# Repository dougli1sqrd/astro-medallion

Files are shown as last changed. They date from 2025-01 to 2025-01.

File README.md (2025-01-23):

# Astro Medallion

Electronics schematics, PCB layout, and software for the Astro Medallion.

The Astro Medallion is a 12 sided circuit board with LEDs that represent the astrological planets and their positions as a sort of clock. Earth is in the middle of 12 spokes of addressable RGB LEDs, where each spoke represents a sky position in the elliptical - each 30 degree section one of the zodiac signs. The distance along each spoke represents the distance away from the each planet is from the earth. Since it's geocentric planets may sometimes be closer or farther away from each other. Each planet will have a unique color.

There are Warm White LEDs along the edge of the PCB which represents the current field of view from your position on Earth - which rotates around the board once every 24 hours.

The project is a kind of translation of this page: https://ericofftherails.city/astrosim/

The LEDs are controlled by an esp32c3 microcontroller on a development board.

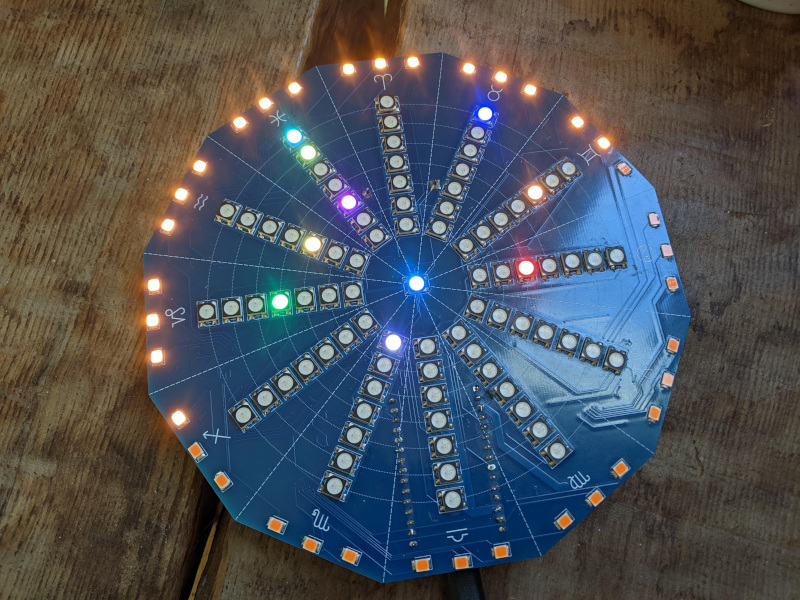
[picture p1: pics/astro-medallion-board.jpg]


# Software

Fundamentally, the software controlling the board needs to:
1. Read the time in the RTC (Real Time Clock) chip on the PCB
2. Calculate Planetary positions
   1. Compute the positions of the planets relative to the earth based on the current time
   2. Compute the "facing" horizon position
3. Update the Display
   1. Send color data to the Addressable LEDs representing where each Planet is with respect to the zodiac sign
   2. Send white LED data representing the current horizon position
4. Sleep, and then awaken in time for the next update

Additionally, the software will have to be configurable mainly in setting the current time. Reading and Writing the current time will go over I2C to the RTC chip on board. This perhaps could be accomplished with a basic serial command line

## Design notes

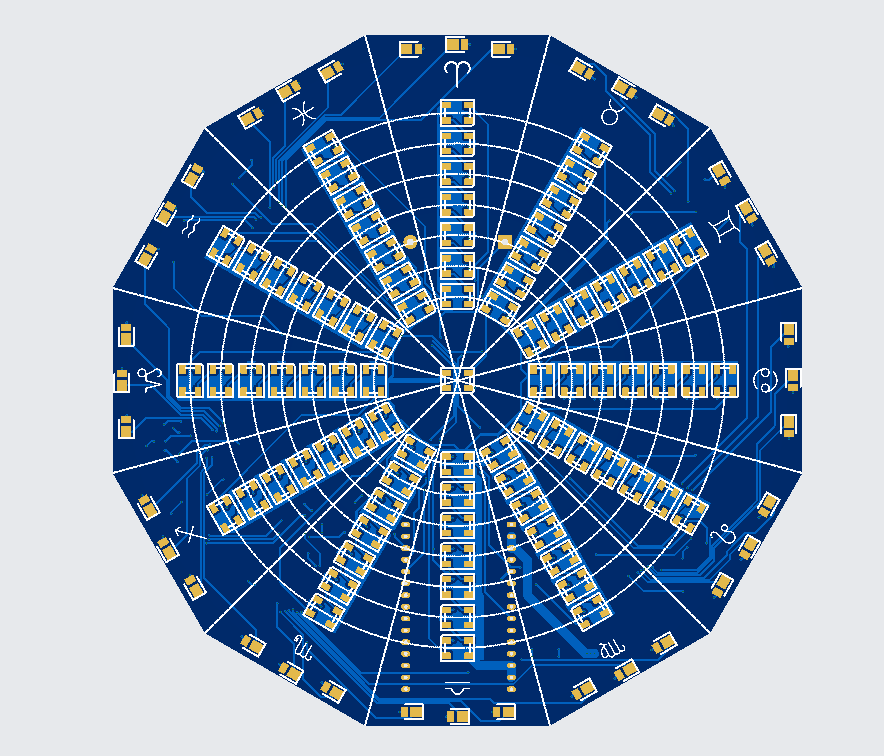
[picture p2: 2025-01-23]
pics/pcb-render.png

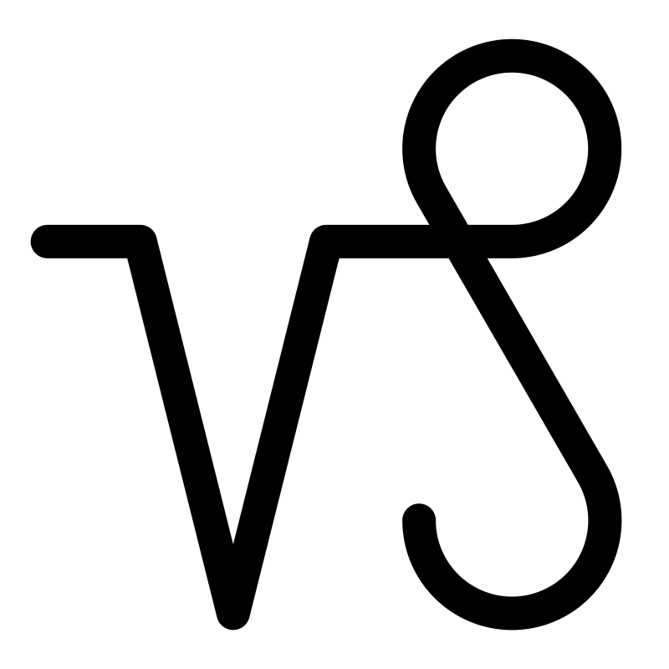
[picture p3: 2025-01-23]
local/Capricornus_symbol_(fixed_width).svg.png

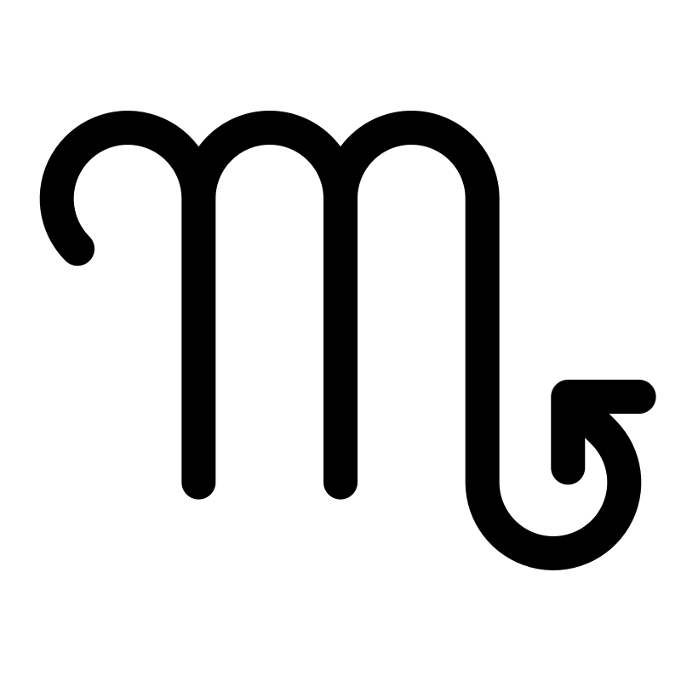
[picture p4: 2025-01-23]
local/Scorpius_symbol_(fixed_width).svg.png

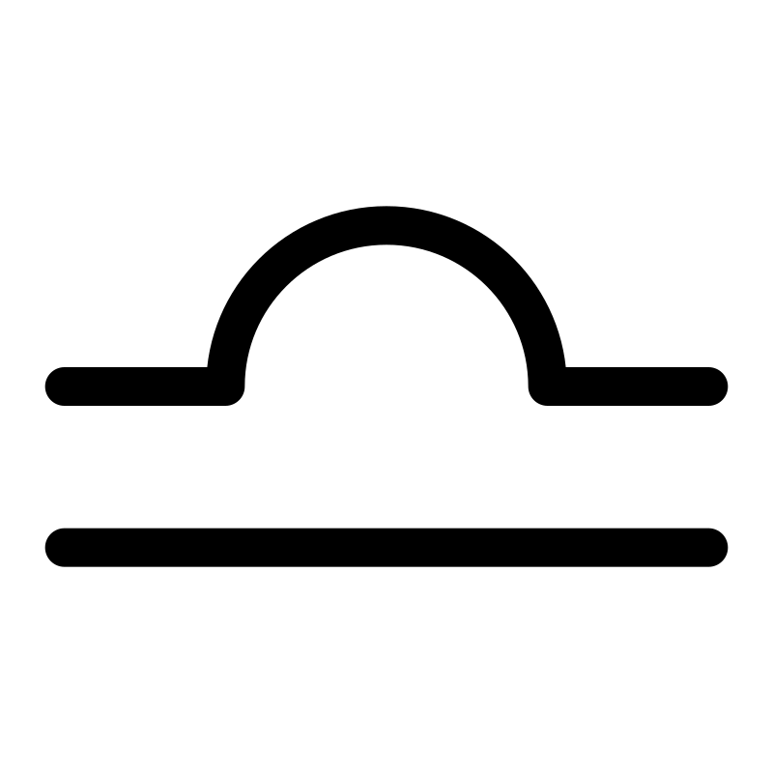
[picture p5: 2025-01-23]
local/Libra_symbol_(fixed_width).svg.png

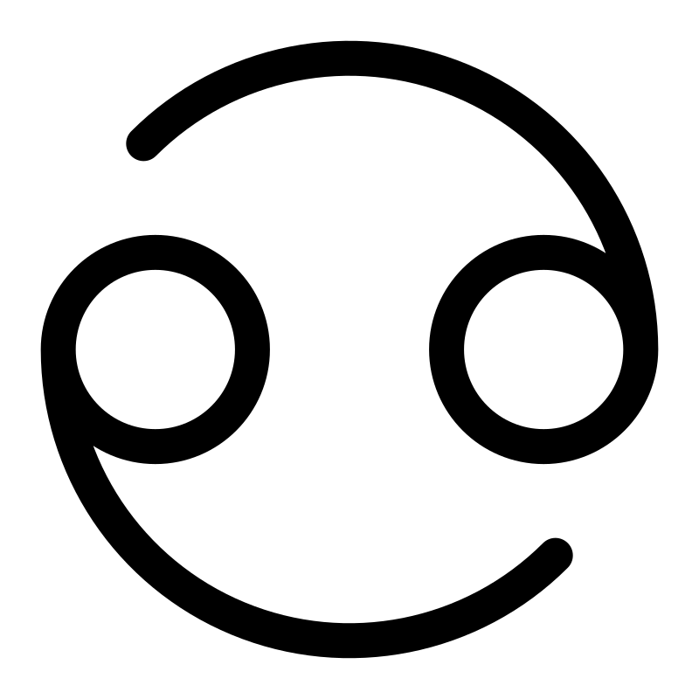
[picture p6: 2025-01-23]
local/Cancer_symbol_(fixed_width).svg.png

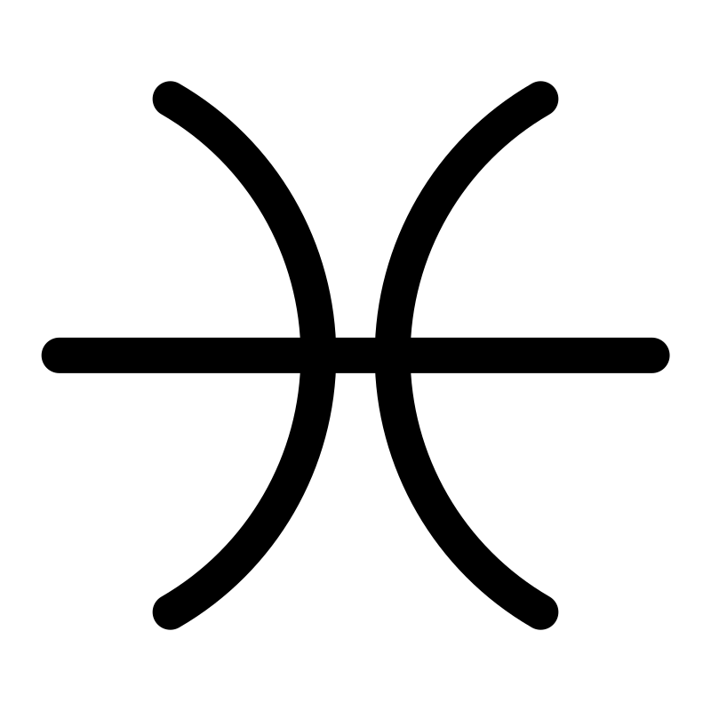
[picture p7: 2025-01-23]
local/Pisces_symbol_(fixed_width).svg.png

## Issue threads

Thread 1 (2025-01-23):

Next Revision Goals

dougli1sqrd, 2025-01-23:
## Hardware
- [ ] Signs in the right order around the sky
- [ ] horizon LEDs are dimmable (connect EN pin the line drivers)
- [ ] Q: Do I need the line drivers?
- [ ] Q: Are there smaller LEDs?
- [ ] Source cheaper RGB LEDs (perhaps a little dimmer?)
- [ ] Q: Assembly by JLC?
- [ ] Mounting Considerations
- [ ] Q: Keep dev board or move to integrated IC?
- [ ] Q: How to input/display Date/Time and Location?

### Stretch
- [ ] lit up signs symbols
- [ ] Battery / charging circuitry?

## Software
- [ ] Correct display code to account for change in sign order
- [ ] Input mode over serial for setting date, time, location, and saving
- [ ] implement any dimming/EN control for horizon

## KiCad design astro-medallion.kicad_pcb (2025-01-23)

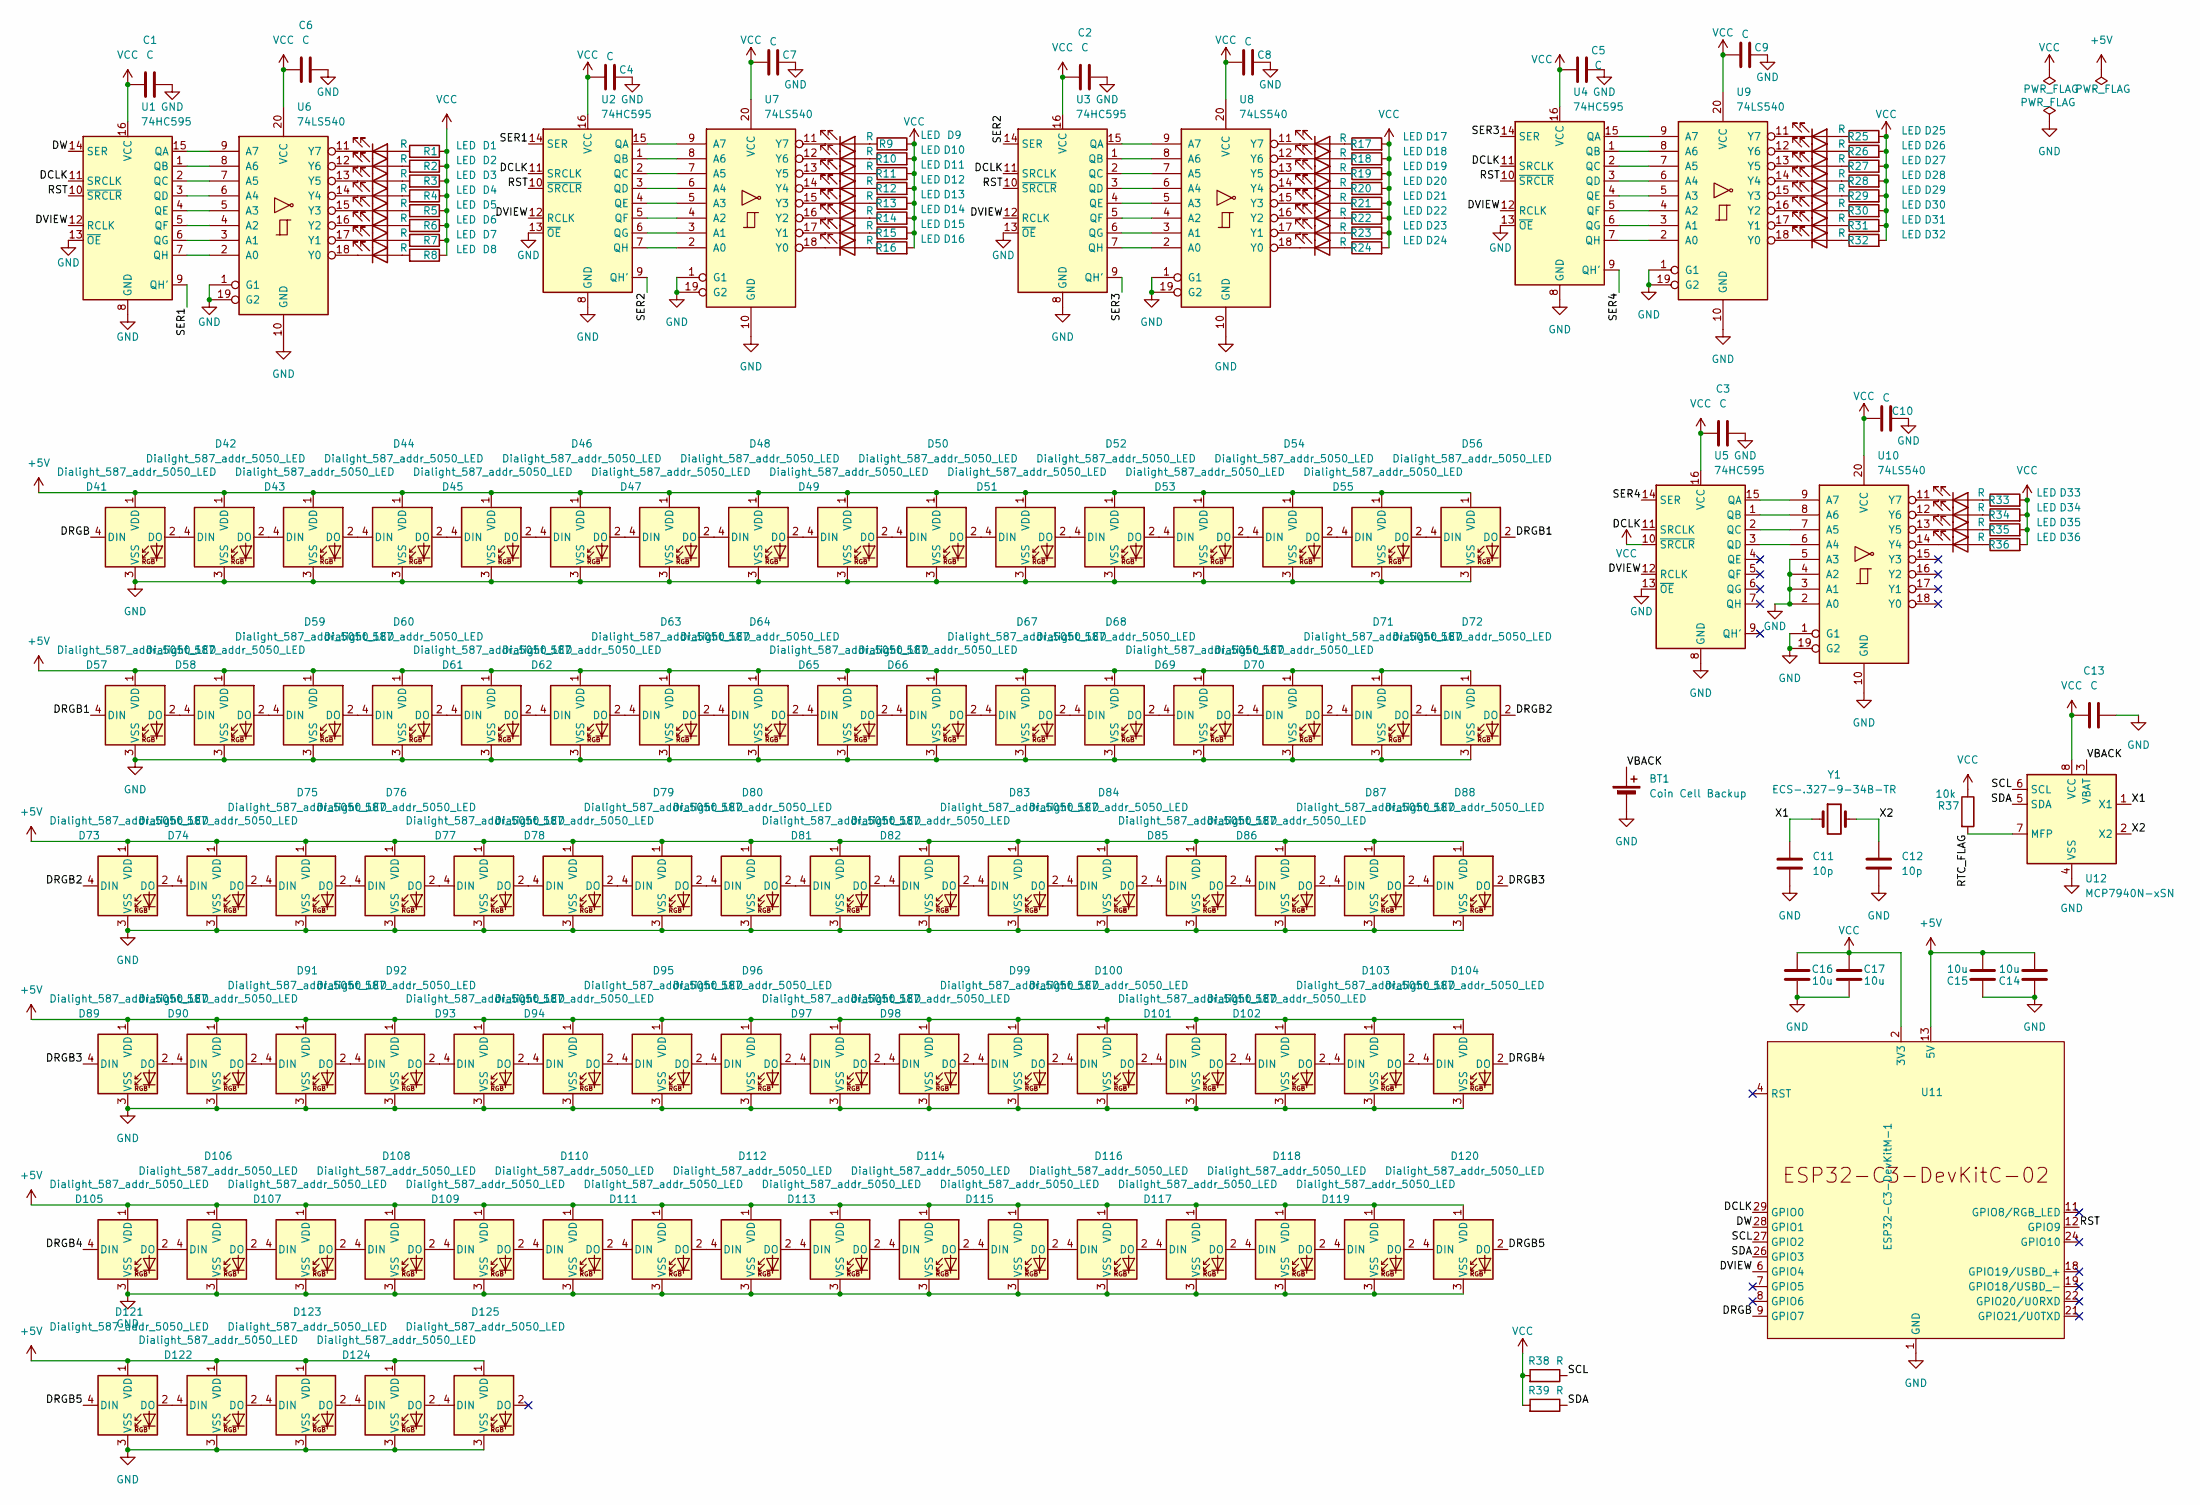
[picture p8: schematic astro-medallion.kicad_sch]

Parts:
BT1: Coin Cell Backup; BatteryHolder_Keystone_103_1x20mm
C1, C2, C3, C4, C5, C6, C7, C8, C9, C10, C13: C; C_0805_2012Metric_Pad1.18x1.45mm_HandSolder
C11, C12: 10p; C_0805_2012Metric_Pad1.18x1.45mm_HandSolder
C14, C15, C16, C17: 10u; C_0805_2012Metric_Pad1.18x1.45mm_HandSolder
D1, D2, D3, D4, D5, D6, D7, D8, D9, D10, D11, D12, D13, D14, D15, D16, D17, D18, D19, D20, D21, D22, D23, D24, D25, D26, D27, D28, D29, D30, D31, D32, D33, D34, D35, D36: LED; LED_PLCC_2835_Handsoldering
D41, D42, D43, D44, D45, D46, D47, D48, D49, D50, D51, D52, D53, D54, D55, D56, D57, D58, D59, D60, D61, D62, D63, D64, D65, D66, D67, D68, D69, D70, D71, D72, D73, D74, D75, D76, D77, D78, D79, D80, D81, D82, D83, D84, D85, D86, D87, D88, D89, D90, D91, D92, D93, D94, D95, D96, D97, D98, D99, D100, D101, D102, D103, D104, D105, D106, D107, D108, D109, D110, D111, D112, D113, D114, D115, D116, D117, D118, D119, D120, D121, D122, D123, D124, D125: Dialight_587_addr_5050_LED; LED_Dialight587_PLCC4_5.0x5.0mm_P3.2mm
R1, R2, R3, R4, R5, R6, R7, R8, R9, R10, R11, R12, R13, R14, R15, R16, R17, R18, R19, R20, R21, R22, R23, R24, R25, R26, R27, R28, R29, R30, R31, R32, R33, R34, R35, R36, R38, R39: R; R_0805_2012Metric_Pad1.20x1.40mm_HandSolder
R37: 10k; R_0805_2012Metric_Pad1.20x1.40mm_HandSolder
U1, U2, U3, U4, U5: 74HC595; TSSOP-16_4.4x5mm_P0.65mm
U6, U7, U8, U9, U10: 74LS540; TSSOP-20_4.4x6.5mm_P0.65mm
U11: ESP32-C3-DevKitM-1; ESP32-C3-DevKitC-02
U12: MCP7940N-xSN; SOIC-8_3.9x4.9mm_P1.27mm
Y1: ECS-.327-9-34B-TR; Crystal_SMD_3215-2Pin_3.2x1.5mm

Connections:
+5V: C14.1, C15.1, D41.1 (VDD), D42.1 (VDD), D43.1 (VDD), D44.1 (VDD), D45.1 (VDD), D46.1 (VDD), D47.1 (VDD), D48.1 (VDD), D49.1 (VDD), D50.1 (VDD), D51.1 (VDD), D52.1 (VDD), D53.1 (VDD), D54.1 (VDD), D55.1 (VDD), D56.1 (VDD), D57.1 (VDD), D58.1 (VDD), D59.1 (VDD), D60.1 (VDD), D61.1 (VDD), D62.1 (VDD), D63.1 (VDD), D64.1 (VDD), D65.1 (VDD), D66.1 (VDD), D67.1 (VDD), D68.1 (VDD), D69.1 (VDD), D70.1 (VDD), D71.1 (VDD), D72.1 (VDD), D73.1 (VDD), D74.1 (VDD), D75.1 (VDD), D76.1 (VDD), D77.1 (VDD), D78.1 (VDD), D79.1 (VDD), D80.1 (VDD), D81.1 (VDD), D82.1 (VDD), D83.1 (VDD), D84.1 (VDD), D85.1 (VDD), D86.1 (VDD), D87.1 (VDD), D88.1 (VDD), D89.1 (VDD), D90.1 (VDD), D91.1 (VDD), D92.1 (VDD), D93.1 (VDD), D94.1 (VDD), D95.1 (VDD), D96.1 (VDD), D97.1 (VDD), D98.1 (VDD), D99.1 (VDD), D100.1 (VDD), D101.1 (VDD), D102.1 (VDD), D103.1 (VDD), D104.1 (VDD), D105.1 (VDD), D106.1 (VDD), D107.1 (VDD), D108.1 (VDD), D109.1 (VDD), D110.1 (VDD), D111.1 (VDD), D112.1 (VDD), D113.1 (VDD), D114.1 (VDD), D115.1 (VDD), D116.1 (VDD), D117.1 (VDD), D118.1 (VDD), D119.1 (VDD), D120.1 (VDD), D121.1 (VDD), D122.1 (VDD), D123.1 (VDD), D124.1 (VDD), D125.1 (VDD), U11.13 (5V), U11.14 (5V)
/DCLK: U1.11 (SRCLK), U2.11 (SRCLK), U3.11 (SRCLK), U4.11 (SRCLK), U5.11 (SRCLK), U11.29 (GPIO0)
/DRGB: D41.4 (DIN), U11.9 (GPIO7)
/DRGB1: D56.2 (DO), D57.4 (DIN)
/DRGB2: D72.2 (DO), D73.4 (DIN)
/DRGB3: D88.2 (DO), D89.4 (DIN)
/DRGB4: D104.2 (DO), D105.4 (DIN)
/DRGB5: D120.2 (DO), D121.4 (DIN)
/DVIEW: U1.12 (RCLK), U2.12 (RCLK), U3.12 (RCLK), U4.12 (RCLK), U5.12 (RCLK), U11.6 (GPIO4)
/DW: U1.14 (SER), U11.28 (GPIO1)
/RST: U1.10 (~SRCLR), U2.10 (~SRCLR), U3.10 (~SRCLR), U4.10 (~SRCLR), U11.12 (GPIO9)
/RTC_FLAG: R37.2, U12.7 (MFP)
/SCL: R38.1, U11.27 (GPIO2), U12.6 (SCL)
/SDA: R39.1, U11.26 (GPIO3), U12.5 (SDA)
/SER1: U1.9 (QH'), U2.14 (SER)
/SER2: U2.9 (QH'), U3.14 (SER)
/SER3: U3.9 (QH'), U4.14 (SER)
/SER4: U4.9 (QH'), U5.14 (SER)
/VBACK: BT1.1 (+), U12.3 (VBAT)
/X1: C11.1, U12.1 (X1), Y1.1
/X2: C12.1, U12.2 (X2), Y1.2
GND: BT1.2 (-), C1.2, C2.2, C3.2, C4.2, C5.2, C6.2, C7.2, C8.2, C9.2, C10.2, C11.2, C12.2, C13.2, C14.2, C15.2, C16.1, C17.1, D41.3 (VSS), D42.3 (VSS), D43.3 (VSS), D44.3 (VSS), D45.3 (VSS), D46.3 (VSS), D47.3 (VSS), D48.3 (VSS), D49.3 (VSS), D50.3 (VSS), D51.3 (VSS), D52.3 (VSS), D53.3 (VSS), D54.3 (VSS), D55.3 (VSS), D56.3 (VSS), D57.3 (VSS), D58.3 (VSS), D59.3 (VSS), D60.3 (VSS), D61.3 (VSS), D62.3 (VSS), D63.3 (VSS), D64.3 (VSS), D65.3 (VSS), D66.3 (VSS), D67.3 (VSS), D68.3 (VSS), D69.3 (VSS), D70.3 (VSS), D71.3 (VSS), D72.3 (VSS), D73.3 (VSS), D74.3 (VSS), D75.3 (VSS), D76.3 (VSS), D77.3 (VSS), D78.3 (VSS), D79.3 (VSS), D80.3 (VSS), D81.3 (VSS), D82.3 (VSS), D83.3 (VSS), D84.3 (VSS), D85.3 (VSS), D86.3 (VSS), D87.3 (VSS), D88.3 (VSS), D89.3 (VSS), D90.3 (VSS), D91.3 (VSS), D92.3 (VSS), D93.3 (VSS), D94.3 (VSS), D95.3 (VSS), D96.3 (VSS), D97.3 (VSS), D98.3 (VSS), D99.3 (VSS), D100.3 (VSS), D101.3 (VSS), D102.3 (VSS), D103.3 (VSS), D104.3 (VSS), D105.3 (VSS), D106.3 (VSS), D107.3 (VSS), D108.3 (VSS), D109.3 (VSS), D110.3 (VSS), D111.3 (VSS), D112.3 (VSS), D113.3 (VSS), D114.3 (VSS), D115.3 (VSS), D116.3 (VSS), D117.3 (VSS), D118.3 (VSS), D119.3 (VSS), D120.3 (VSS), D121.3 (VSS), D122.3 (VSS), D123.3 (VSS), D124.3 (VSS), D125.3 (VSS), U1.8 (GND), U1.13 (~OE), U2.8 (GND), U2.13 (~OE), U3.8 (GND), U3.13 (~OE), U4.8 (GND), U4.13 (~OE), U5.8 (GND), U5.13 (~OE), U6.1 (G1), U6.10 (GND), U6.19 (G2), U7.1 (G1), U7.10 (GND), U7.19 (G2), U8.1 (G1), U8.10 (GND), U8.19 (G2), U9.1 (G1), U9.10 (GND), U9.19 (G2), U10.1 (G1), U10.2 (A0), U10.3 (A1), U10.4 (A2), U10.5 (A3), U10.10 (GND), U10.19 (G2), U11.1 (GND), U11.5 (GND), U11.10 (GND), U11.15 (GND), U11.16 (GND), U11.17 (GND), U11.20 (GND), U11.23 (GND), U11.25 (GND), U11.30 (GND), U12.4 (VSS)
unnamed: D1.2 (A), R1.2
unnamed: D1.1 (K), U6.11 (Y7)
unnamed: D2.2 (A), R2.2
unnamed: D2.1 (K), U6.12 (Y6)
unnamed: D3.2 (A), R3.2
unnamed: D3.1 (K), U6.13 (Y5)
unnamed: D4.2 (A), R4.2
unnamed: D4.1 (K), U6.14 (Y4)
unnamed: D5.2 (A), R5.2
unnamed: D5.1 (K), U6.15 (Y3)
unnamed: D6.2 (A), R6.2
unnamed: D6.1 (K), U6.16 (Y2)
unnamed: D7.2 (A), R7.2
unnamed: D7.1 (K), U6.17 (Y1)
unnamed: D8.2 (A), R8.2
unnamed: D8.1 (K), U6.18 (Y0)
unnamed: D9.2 (A), R9.1
unnamed: D9.1 (K), U7.11 (Y7)
unnamed: D10.2 (A), R10.1
unnamed: D10.1 (K), U7.12 (Y6)
unnamed: D11.2 (A), R11.1
unnamed: D11.1 (K), U7.13 (Y5)
unnamed: D12.2 (A), R12.1
unnamed: D12.1 (K), U7.14 (Y4)
unnamed: D13.2 (A), R13.1
unnamed: D13.1 (K), U7.15 (Y3)
unnamed: D14.2 (A), R14.1
unnamed: D14.1 (K), U7.16 (Y2)
unnamed: D15.2 (A), R15.1
unnamed: D15.1 (K), U7.17 (Y1)
unnamed: D16.2 (A), R16.1
unnamed: D16.1 (K), U7.18 (Y0)
unnamed: D17.2 (A), R17.1
unnamed: D17.1 (K), U8.11 (Y7)
unnamed: D18.2 (A), R18.1
unnamed: D18.1 (K), U8.12 (Y6)
unnamed: D19.2 (A), R19.1
unnamed: D19.1 (K), U8.13 (Y5)
unnamed: D20.2 (A), R20.1
unnamed: D20.1 (K), U8.14 (Y4)
unnamed: D21.2 (A), R21.1
unnamed: D21.1 (K), U8.15 (Y3)
unnamed: D22.2 (A), R22.1
unnamed: D22.1 (K), U8.16 (Y2)
unnamed: D23.2 (A), R23.1
unnamed: D23.1 (K), U8.17 (Y1)
unnamed: D24.2 (A), R24.1
unnamed: D24.1 (K), U8.18 (Y0)
unnamed: D25.2 (A), R25.1
unnamed: D25.1 (K), U9.11 (Y7)
unnamed: D26.2 (A), R26.1
unnamed: D26.1 (K), U9.12 (Y6)
unnamed: D27.2 (A), R27.1
unnamed: D27.1 (K), U9.13 (Y5)
unnamed: D28.2 (A), R28.1
unnamed: D28.1 (K), U9.14 (Y4)
unnamed: D29.2 (A), R29.1
unnamed: D29.1 (K), U9.15 (Y3)
unnamed: D30.2 (A), R30.1
unnamed: D30.1 (K), U9.16 (Y2)
unnamed: D31.2 (A), R31.1
unnamed: D31.1 (K), U9.17 (Y1)
unnamed: D32.2 (A), R32.1
unnamed: D32.1 (K), U9.18 (Y0)
unnamed: D33.2 (A), R33.1
unnamed: D33.1 (K), U10.11 (Y7)
unnamed: D34.2 (A), R34.1
unnamed: D34.1 (K), U10.12 (Y6)
unnamed: D35.2 (A), R35.1
unnamed: D35.1 (K), U10.13 (Y5)
unnamed: D36.2 (A), R36.1
unnamed: D36.1 (K), U10.14 (Y4)
unnamed: D41.2 (DO), D42.4 (DIN)
unnamed: D42.2 (DO), D43.4 (DIN)
unnamed: D43.2 (DO), D44.4 (DIN)
unnamed: D44.2 (DO), D45.4 (DIN)
unnamed: D45.2 (DO), D46.4 (DIN)
unnamed: D46.2 (DO), D47.4 (DIN)
unnamed: D47.2 (DO), D48.4 (DIN)
unnamed: D48.2 (DO), D49.4 (DIN)
unnamed: D49.2 (DO), D50.4 (DIN)
unnamed: D50.2 (DO), D51.4 (DIN)
unnamed: D51.2 (DO), D52.4 (DIN)
unnamed: D52.2 (DO), D53.4 (DIN)
unnamed: D53.2 (DO), D54.4 (DIN)
unnamed: D54.2 (DO), D55.4 (DIN)
unnamed: D55.2 (DO), D56.4 (DIN)
unnamed: D57.2 (DO), D58.4 (DIN)
unnamed: D58.2 (DO), D59.4 (DIN)
unnamed: D59.2 (DO), D60.4 (DIN)
unnamed: D60.2 (DO), D61.4 (DIN)
unnamed: D61.2 (DO), D62.4 (DIN)
unnamed: D62.2 (DO), D63.4 (DIN)
unnamed: D63.2 (DO), D64.4 (DIN)
unnamed: D64.2 (DO), D65.4 (DIN)
unnamed: D65.2 (DO), D66.4 (DIN)
unnamed: D66.2 (DO), D67.4 (DIN)
unnamed: D67.2 (DO), D68.4 (DIN)
unnamed: D68.2 (DO), D69.4 (DIN)
unnamed: D69.2 (DO), D70.4 (DIN)
unnamed: D70.2 (DO), D71.4 (DIN)
unnamed: D71.2 (DO), D72.4 (DIN)
unnamed: D73.2 (DO), D74.4 (DIN)
unnamed: D74.2 (DO), D75.4 (DIN)
unnamed: D75.2 (DO), D76.4 (DIN)
unnamed: D76.2 (DO), D77.4 (DIN)
unnamed: D77.2 (DO), D78.4 (DIN)
unnamed: D78.2 (DO), D79.4 (DIN)
unnamed: D79.2 (DO), D80.4 (DIN)
unnamed: D80.2 (DO), D81.4 (DIN)
unnamed: D81.2 (DO), D82.4 (DIN)
unnamed: D82.2 (DO), D83.4 (DIN)
unnamed: D83.2 (DO), D84.4 (DIN)
unnamed: D84.2 (DO), D85.4 (DIN)
unnamed: D85.2 (DO), D86.4 (DIN)
unnamed: D86.2 (DO), D87.4 (DIN)
unnamed: D87.2 (DO), D88.4 (DIN)
unnamed: D89.2 (DO), D90.4 (DIN)
unnamed: D90.2 (DO), D91.4 (DIN)
unnamed: D91.2 (DO), D92.4 (DIN)
unnamed: D92.2 (DO), D93.4 (DIN)
unnamed: D93.2 (DO), D94.4 (DIN)
unnamed: D94.2 (DO), D95.4 (DIN)
unnamed: D95.2 (DO), D96.4 (DIN)
unnamed: D96.2 (DO), D97.4 (DIN)
unnamed: D97.2 (DO), D98.4 (DIN)
unnamed: D98.2 (DO), D99.4 (DIN)
unnamed: D99.2 (DO), D100.4 (DIN)
unnamed: D100.2 (DO), D101.4 (DIN)
unnamed: D101.2 (DO), D102.4 (DIN)
unnamed: D102.2 (DO), D103.4 (DIN)
unnamed: D103.2 (DO), D104.4 (DIN)
unnamed: D105.2 (DO), D106.4 (DIN)
unnamed: D106.2 (DO), D107.4 (DIN)
unnamed: D107.2 (DO), D108.4 (DIN)
unnamed: D108.2 (DO), D109.4 (DIN)
unnamed: D109.2 (DO), D110.4 (DIN)
unnamed: D110.2 (DO), D111.4 (DIN)
unnamed: D111.2 (DO), D112.4 (DIN)
unnamed: D112.2 (DO), D113.4 (DIN)
unnamed: D113.2 (DO), D114.4 (DIN)
unnamed: D114.2 (DO), D115.4 (DIN)
unnamed: D115.2 (DO), D116.4 (DIN)
unnamed: D116.2 (DO), D117.4 (DIN)
unnamed: D117.2 (DO), D118.4 (DIN)
unnamed: D118.2 (DO), D119.4 (DIN)
unnamed: D119.2 (DO), D120.4 (DIN)
unnamed: D121.2 (DO), D122.4 (DIN)
unnamed: D122.2 (DO), D123.4 (DIN)
unnamed: D123.2 (DO), D124.4 (DIN)
unnamed: D124.2 (DO), D125.4 (DIN)
unnamed: U1.15 (QA), U6.9 (A7)
unnamed: U1.1 (QB), U6.8 (A6)
unnamed: U1.2 (QC), U6.7 (A5)
unnamed: U1.3 (QD), U6.6 (A4)
unnamed: U1.4 (QE), U6.5 (A3)
unnamed: U1.5 (QF), U6.4 (A2)
unnamed: U1.6 (QG), U6.3 (A1)
unnamed: U1.7 (QH), U6.2 (A0)
unnamed: U2.15 (QA), U7.9 (A7)
unnamed: U2.1 (QB), U7.8 (A6)
unnamed: U2.2 (QC), U7.7 (A5)
unnamed: U2.3 (QD), U7.6 (A4)
unnamed: U2.4 (QE), U7.5 (A3)
unnamed: U2.5 (QF), U7.4 (A2)
unnamed: U2.6 (QG), U7.3 (A1)
unnamed: U2.7 (QH), U7.2 (A0)
unnamed: U3.15 (QA), U8.9 (A7)
unnamed: U3.1 (QB), U8.8 (A6)
unnamed: U3.2 (QC), U8.7 (A5)
unnamed: U3.3 (QD), U8.6 (A4)
unnamed: U3.4 (QE), U8.5 (A3)
unnamed: U3.5 (QF), U8.4 (A2)
unnamed: U3.6 (QG), U8.3 (A1)
unnamed: U3.7 (QH), U8.2 (A0)
unnamed: U4.15 (QA), U9.9 (A7)
unnamed: U4.1 (QB), U9.8 (A6)
unnamed: U4.2 (QC), U9.7 (A5)
unnamed: U4.3 (QD), U9.6 (A4)
unnamed: U4.4 (QE), U9.5 (A3)
unnamed: U4.5 (QF), U9.4 (A2)
unnamed: U4.6 (QG), U9.3 (A1)
unnamed: U4.7 (QH), U9.2 (A0)
unnamed: U5.3 (QD), U10.6 (A4)
unnamed: U5.2 (QC), U10.7 (A5)
unnamed: U5.1 (QB), U10.8 (A6)
unnamed: U5.15 (QA), U10.9 (A7)
VCC: C1.1, C2.1, C3.1, C4.1, C5.1, C6.1, C7.1, C8.1, C9.1, C10.1, C13.1, C16.2, C17.2, R1.1, R2.1, R3.1, R4.1, R5.1, R6.1, R7.1, R8.1, R9.2, R10.2, R11.2, R12.2, R13.2, R14.2, R15.2, R16.2, R17.2, R18.2, R19.2, R20.2, R21.2, R22.2, R23.2, R24.2, R25.2, R26.2, R27.2, R28.2, R29.2, R30.2, R31.2, R32.2, R33.2, R34.2, R35.2, R36.2, R37.1, R38.2, R39.2, U1.16 (VCC), U2.16 (VCC), U3.16 (VCC), U4.16 (VCC), U5.10 (~SRCLR), U5.16 (VCC), U6.20 (VCC), U7.20 (VCC), U8.20 (VCC), U9.20 (VCC), U10.20 (VCC), U11.2 (3V3), U11.3 (3V3), U12.8 (VCC)

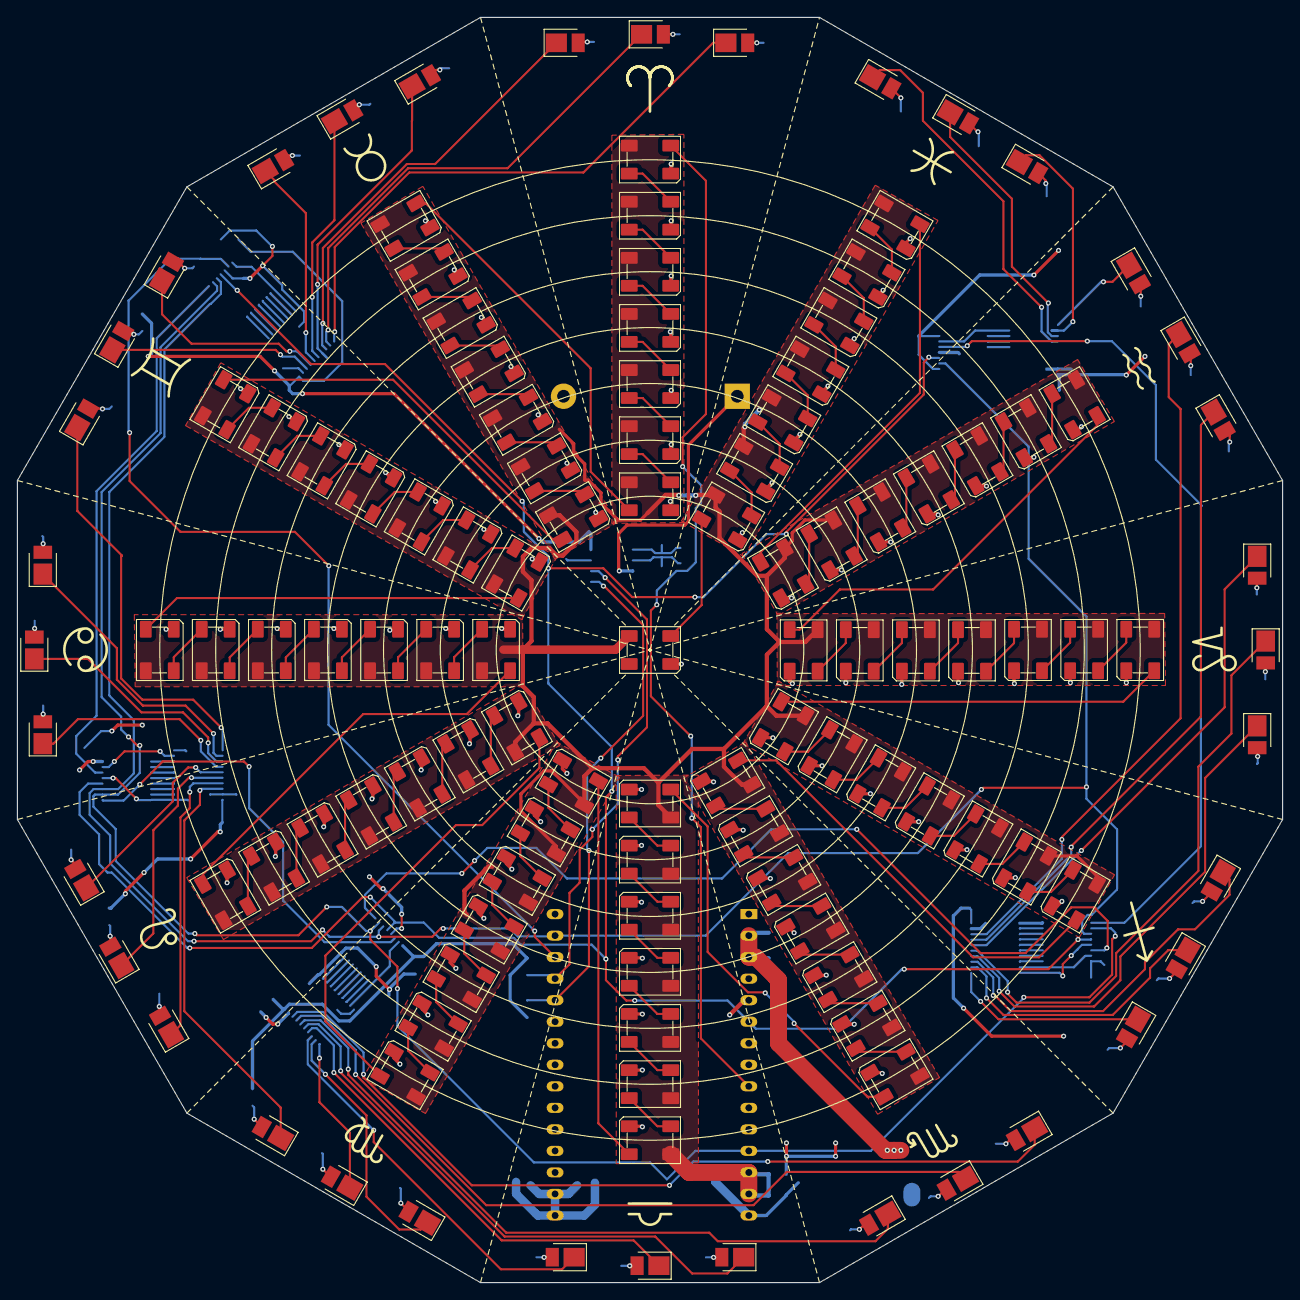
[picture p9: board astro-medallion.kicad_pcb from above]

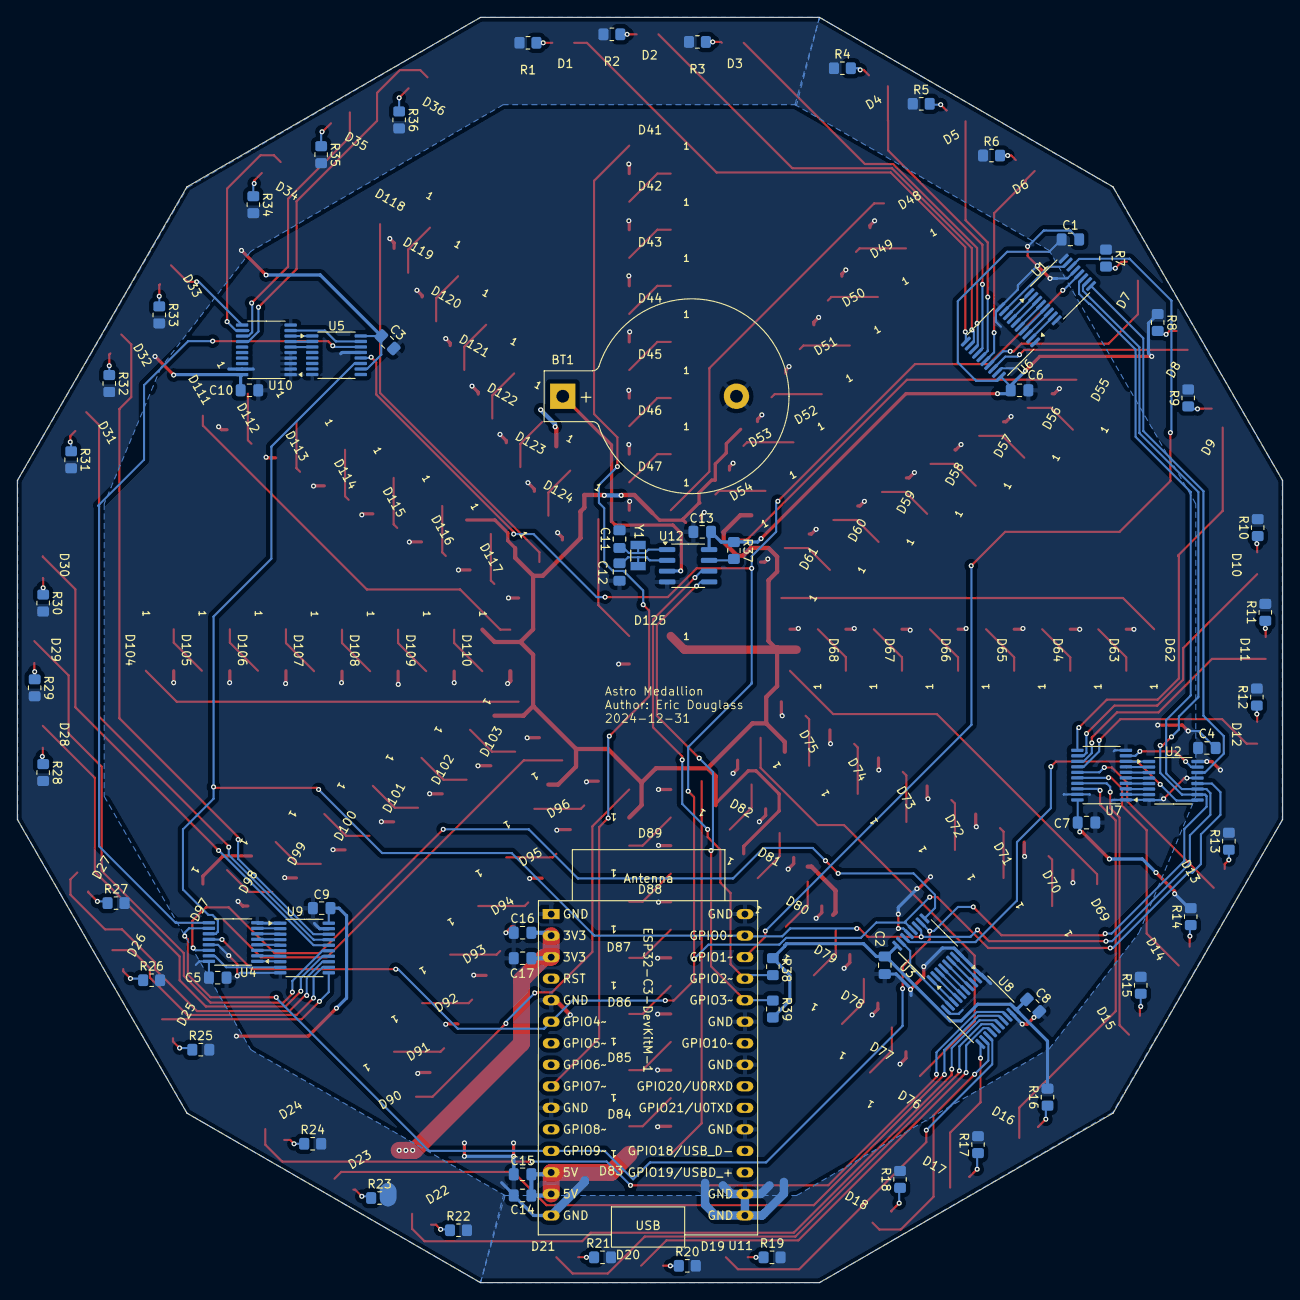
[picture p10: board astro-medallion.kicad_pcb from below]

Board: 2 copper layers, 149.3 x 149.3 mm, 191 parts (70 on the bottom side), 210 nets.

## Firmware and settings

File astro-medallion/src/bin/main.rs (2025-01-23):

#![no_std]
#![no_main]

use core::cell::RefCell;
use core::f64;
use core::ops::{AddAssign, Deref};

use astro_medallion::{int_to_month, SpiFesOnlyWrite};
use astro_medallion_lib::astro::time::Month;
use astro_medallion_lib::astronomy::{
    east_horizon_alt, horizon_longitudes, jd, within_2pi, zenith,
};
use astro_medallion_lib::display::{
    lerp_rgb, DirectHorizonControl, HorizonDisplay, Planets, BLACK,
};
use astro_medallion_lib::rgb::RGBWrite;
use chrono::TimeDelta;
use critical_section::Mutex;
use esp_backtrace as _;
use esp_hal::gpio::{Level, Output};
use esp_hal::i2c::master::I2c;
use esp_hal::interrupt::Priority;
use esp_hal::peripheral::Peripheral;
use esp_hal::peripherals::{Interrupt, TIMG0};
use esp_hal::riscv::asm::wfi;
use esp_hal::spi::master::{Config, Spi};
use esp_hal::spi::SpiMode;
use esp_hal::timer::timg::{Timer, TimerGroup, TimerX};
use esp_hal::uart::{Uart, UartRx, UartTx};
use esp_hal::{i2c, interrupt, prelude::*, Blocking};
use esp_println::println;
use mcp794xx::ic::Mcp7940n;
use mcp794xx::interface::I2cInterface;
use mcp794xx::{DateTimeAccess, Datelike, Mcp794xx, NaiveDate, Timelike};
use nb::block;

extern crate alloc;

const TIME_SET: u8 = 0x54;
const DEFAULT_YMD: (i32, u32, u32) = (2025, 1, 17);
const DEFAULT_HMS: (u32, u32, u32) = (23, 0, 0);
const UPDATE_INTERVAL: u64 = 1000 * 60 * 20;
// const UPDATE_INTERVAL: u64 = 1000;
const WAKEUP_INTERVAL: u64 = 10;

static TIMER0: Mutex<RefCell<Option<Timer<TimerX<TIMG0>, Blocking>>>> =
    Mutex::new(RefCell::new(None));

static CURRENT_DURATION: Mutex<RefCell<u64>> = Mutex::new(RefCell::new(0));

#[entry]
fn main() -> ! {
    let peripherals = esp_hal::init({
        let mut config = esp_hal::Config::default();
        config.cpu_clock = CpuClock::max();
        config
    });

    esp_println::logger::init_logger_from_env();

    esp_alloc::heap_allocator!(92 * 1024);

    let scl = peripherals.GPIO2;
    let sda = peripherals.GPIO3;
    let i2c = I2c::new(
        peripherals.I2C0,
        i2c::master::Config {
            ..Default::default()
        },
    )
    .with_scl(scl)
    .with_sda(sda);
    let mut rtc = mcp794xx::Mcp794xx::new_mcp7940n(i2c);

    rtc.enable().unwrap();
    rtc.enable_backup_battery_power().unwrap();

    // Set the time if it's not been set yet
    if rtc.read_sram_byte(0x20).unwrap() != TIME_SET {
        // READ the first byte in SRAM, and look for the TIME_SET byte.
        // if it's not there it means we need to set the time
        rtc.disable().unwrap();
        // Wait for oscillator to stop
        while rtc.is_oscillator_running().unwrap() {}

        rtc.set_datetime(
            &NaiveDate::from_ymd_opt(DEFAULT_YMD.0, DEFAULT_YMD.1, DEFAULT_YMD.2)
                .unwrap()
                .and_hms_opt(DEFAULT_HMS.0, DEFAULT_HMS.1, DEFAULT_HMS.2)
                .unwrap(),
        )
        .unwrap();
        rtc.enable().unwrap();
        rtc.write_sram_byte(0x20, TIME_SET).unwrap();
    }

    let timg0 = TimerGroup::new(peripherals.TIMG0);
    let timer0: Timer<
        esp_hal::timer::timg::TimerX<<esp_hal::peripherals::TIMG0 as Peripheral>::P>,
        Blocking,
    > = timg0.timer0;
    timer0.set_interrupt_handler(timer_interrupt);

    interrupt::enable(Interrupt::TG0_T0_LEVEL, Priority::Priority1).unwrap();
    timer0.load_value(WAKEUP_INTERVAL.millis()).unwrap();
    timer0.start();
    timer0.listen();
    critical_section::with(|cs| {
        TIMER0.borrow(cs).replace(Some(timer0));
    });

    let gpio07 = peripherals.GPIO7;

    let config = Config {
        frequency: 6667.kHz(),
        mode: SpiMode::Mode0,
        ..Default::default()
    };
    let mut spi = Spi::new(peripherals.SPI2).with_mosi(gpio07);

    spi.apply_config(&config).unwrap();

    let rgb_spi = SpiFesOnlyWrite(spi);
    let rgbWrite = RGBWrite::new(rgb_spi);
    let mut planets = Planets::new(rgbWrite);

    let clock = Output::new(peripherals.GPIO0, Level::Low);
    let data = Output::new(peripherals.GPIO1, Level::Low);
    let flush = Output::new(peripherals.GPIO4, Level::Low);
    let reset = Output::new(peripherals.GPIO9, Level::High);

    let mut hc = DirectHorizonControl::new(clock, data, flush, reset);
    hc.reset();
    hc.update();

    let mut horizon = HorizonDisplay::new(hc);

    let lat = 37.77_f64.to_radians();
    let lon = -122.0_f64.to_radians();
    let mut i = 0;

    critical_section::with(|_| {
        update_display(&mut rtc, lat, lon, &mut horizon, &mut planets);
    });

    let mut lerp_t = 0;
    let max_lerp = 200;

    loop {
        // Read the current duration, and if we're greater than the update UPDATE_INTERVAL,
        // then reset the duration and and read the real time clock and update as normal
        let update: bool = critical_section::with(|cs| {
            let mut d = CURRENT_DURATION.borrow(cs).borrow_mut();
            let update = *d >= UPDATE_INTERVAL;
            if update {
                *d = 0;
            }
            update
        });
        if update {
            critical_section::with(|_| {
                update_display(&mut rtc, lat, lon, &mut horizon, &mut planets);
                // update_display_demo(&mut rtc, lat, lon, &mut horizon, &mut planets, time_delta);
                println!("Update {i}");
                i += 1;
                // let tt = 15 + 15*i + i*i*i / 6;
                // println!("Delta T minutes = {tt}, dt = {}", tt - time_delta);
                // time_delta = tt;
            });
        }
        for mut d in planets.dupes() {
            // println!("dupes = {:?}", d);
            for i in 0..d.len() {
                let n = (i + 1) % d.len();
                // If we have two planets overlapping, that takes precedent over a planet transiting
                d[n].t_max = None;
                if lerp_t < max_lerp {
                    d[n].color = lerp_rgb(d[n].base, d[i].base, lerp_t, max_lerp);
                } else {
                    d[n].color = lerp_rgb(d[i].base, d[n].base, lerp_t - max_lerp, max_lerp);
                }
            }
        }

        for p in planets.slice_mut() {
            if let Some(t_max) = p.t_max {
                p.t = (p.t + 1) % (2 * t_max);
                // println!("t_max = {t_max}, t = {}", p.t);
                if p.t < t_max {
                    p.color = lerp_rgb(p.base, BLACK, p.t, t_max);
                } else {
                    p.color = lerp_rgb(BLACK, p.base, p.t - t_max, t_max);
                }
            }
        }
        let s = planets.sequence();
        planets.rgb_write.write(&s);

        lerp_t = (lerp_t + 1) % (2 * max_lerp);

        wfi();
    }
}

#[handler]
fn timer_interrupt() {
    critical_section::with(|cs| {
        if let Some(t) = TIMER0.borrow(cs).borrow().deref() {
            t.clear_interrupt();
            t.load_value(WAKEUP_INTERVAL.millis()).unwrap();
            t.start();
        }
        // Update the wakeup duration
        CURRENT_DURATION
            .borrow(cs)
            .borrow_mut()
            .add_assign(WAKEUP_INTERVAL);
    });
}

fn update_display(
    rtc: &mut Mcp794xx<I2cInterface<I2c<'_, Blocking>>, Mcp7940n>,
    lat: f64,
    lon: f64,
    horizon: &mut HorizonDisplay<Output<'_>, Output<'_>, Output<'_>, Output<'_>>,
    planets: &mut Planets<SpiFesOnlyWrite<'_>>,
) {
    let current_time = rtc.datetime().unwrap();
    // let current_time = NaiveDate::from_ymd_opt(2025, 4, 18).unwrap().and_time(NaiveTime::from_hms_opt(16, 45, 0).unwrap());
    println!("Reading time as {}", current_time);
    let jd = jd(
        current_time.year() as i16,
        int_to_month(current_time.month(), Month::Jan),
        current_time.day() as u8,
        current_time.hour() as u8,
        current_time.minute() as u8,
        current_time.second() as f64,
        -8.0,
    );
    let (east, west) = horizon_longitudes(jd, lon, lat);
    let alt_east = east_horizon_alt(jd, lon, lat);
    let alt_west = within_2pi(alt_east + f64::consts::PI);
    let z = zenith(jd, lon, lat);
    println!(
        "East: {}, Z: {}, West: {}",
        east.to_degrees(),
        z.long.to_degrees(),
        west.to_degrees()
    );
    println!(
        "AltEast: {}, AltWest: {}",
        alt_east.to_degrees(),
        alt_west.to_degrees()
    );
    horizon.light_start_end(alt_east, alt_west);

    let _ = planets.update_date(jd);

    let s = planets.sequence();
    planets.rgb_write.reset();
    planets.rgb_write.write(&s);
}

#[allow(unused)]
fn update_display_demo(
    rtc: &mut Mcp794xx<I2cInterface<I2c<'_, Blocking>>, Mcp7940n>,
    lat: f64,
    lon: f64,
    horizon: &mut HorizonDisplay<Output<'_>, Output<'_>, Output<'_>, Output<'_>>,
    planets: &mut Planets<SpiFesOnlyWrite<'_>>,
    add_min: i64,
) {
    let current_time = rtc
        .datetime()
        .unwrap()
        .checked_add_signed(TimeDelta::minutes(add_min))
        .unwrap();
    // let current_time = NaiveDate::from_ymd_opt(2025, 4, 18).unwrap().and_time(NaiveTime::from_hms_opt(16, 45, 0).unwrap());
    println!("Reading time as {}", current_time);
    let jd = jd(
        current_time.year() as i16,
        int_to_month(current_time.month(), Month::Jan),
        current_time.day() as u8,
        current_time.hour() as u8,
        current_time.minute() as u8,
        current_time.second() as f64,
        -8.0,
    );
    let (east, west) = horizon_longitudes(jd, lon, lat);
    let alt_east = east_horizon_alt(jd, lon, lat);
    let alt_west = within_2pi(alt_east + f64::consts::PI);
    let z = zenith(jd, lon, lat);
    println!(
        "East: {}, Z: {}, West: {}",
        east.to_degrees(),
        z.long.to_degrees(),
        west.to_degrees()
    );
    println!(
        "AltEast: {}, AltWest: {}",
        alt_east.to_degrees(),
        alt_west.to_degrees()
    );
    horizon.light_start_end(alt_east, alt_west);

    let _ = planets.update_date(jd);

    let s = planets.sequence();
    planets.rgb_write.reset();
    planets.rgb_write.write(&s);
}

struct UartWrapper<'d, M> {
    pub rx: UartRx<'d, M>,
    pub tx: UartTx<'d, M>,
}

impl<'a, M> From<Uart<'a, M>> for UartWrapper<'a, M>
where
    M: esp_hal::Mode,
{
    fn from(value: Uart<'a, M>) -> Self {
        let (rx, tx) = value.split();

        Self { rx, tx }
    }
}

#[allow(unused)]
#[derive(Debug)]
struct Error(esp_hal::uart::Error);

impl From<esp_hal::uart::Error> for Error {
    fn from(value: esp_hal::uart::Error) -> Self {
        Self(value)
    }
}

impl embedded_io::Error for Error {
    fn kind(&self) -> embedded_io::ErrorKind {
        embedded_io::ErrorKind::Other
    }
}

impl<M> embedded_io::ErrorType for UartWrapper<'_, M> {
    type Error = Error;
}

impl<M: esp_hal::Mode> embedded_io::Read for UartWrapper<'_, M> {
    fn read(&mut self, buf: &mut [u8]) -> Result<usize, Self::Error> {
        buf[0] = block!(self.rx.read_byte())?;

        Ok(1 + self.rx.drain_fifo(&mut buf[1..]))
    }
}

impl<M: esp_hal::Mode> embedded_io::Write for UartWrapper<'_, M> {
    fn write(&mut self, buf: &[u8]) -> Result<usize, Self::Error> {
        self.tx.write_bytes(buf).map_err(Self::Error::from)
    }

    fn flush(&mut self) -> Result<(), Self::Error> {
        block!(self.tx.flush_tx()).map_err(Self::Error::from)
    }
}

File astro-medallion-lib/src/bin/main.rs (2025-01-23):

use core::f64;

use astro::{
    angle::{hms_frm_deg, limit_to_360},
    coords::{self, EclPoint},
    ecl_frm_eq,
    ecliptic::mn_oblq_IAU,
    eq_frm_ecl,
    planet::geocent_geomet_ecl_coords,
    time::mn_sidr,
};
use astro_medallion_lib::astronomy::{east_horizon, eq_from_hz, west_horizon, zenith, Within2Pi};
use vsop87::vsop87b;

fn main() {
    println!("hello");

    let day_of_month = astro::time::DayOfMonth {
        day: 5,
        hr: 13,
        min: 28,
        sec: 4.0,
        time_zone: -8.0,
    };

    let date = astro::time::Date {
        year: 2025,
        month: astro::time::Month::Jan,
        decimal_day: astro::time::decimal_day(&day_of_month),
        cal_type: astro::time::CalType::Gregorian,
    };

    let julian_day = astro::time::julian_day(&date);

    // for higher accuracy in specifying the time of interest,
    // find the Julian Ephemeris day; this slightly differs from
    // the Julian day by ΔT, which is usually a few seconds. you
    // can get a reported value of it from the Astronomical
    // Almanac, or calculate it using the built-in function

    let delta_t = astro::time::delta_t(date.year.into(), date.month as u8);

    let julian_ephm_day = astro::time::julian_ephemeris_day(julian_day, delta_t);

    // let (sun_ecl_point, rad_vec_sun) = astro::sun::geocent_ecl_pos(julian_ephm_day);

    let tilt = astro::ecliptic::mn_oblq_IAU(julian_ephm_day);
    // let (asc, dec) = eq_frm_ecl!(sun_ecl_point.long, sun_ecl_point.lat, tilt);

    // println!(
    //     "Sun pos (equatorial): ({}, {})",
    //     asc * 180.0 / core::f64::consts::PI,
    //     dec * 180.0 / core::f64::consts::PI
    // );
    // println!("Sun distance: {rad_vec_sun}");

    // let (mars_pos, mars_r) =
    //     astro::planet::geocent_apprnt_ecl_coords(&astro::planet::Planet::Mars, julian_ephm_day);
    // let (mars_asc, mars_dec) = eq_frm_ecl!(mars_pos.long, mars_pos.lat, tilt);
    // println!(
    //     "Mars pos (equatorial): ({}, {})",
    //     mars_asc * 180.0 / core::f64::consts::PI,
    //     mars_dec * 180.0 / core::f64::consts::PI
    // );
    // println!("Mars distance: {mars_r}");

    let gsd = astro::time::mn_sidr(julian_ephm_day); //radians
    println!("gsd = {}", gsd);
    let local_long = -122.4;
    let local_sd = gsd + local_long * f64::consts::PI / 180.0;
    println!("local sd = {}", local_sd);
    let lat = 37.77_f64.to_radians();
    println!("obs_dec = {}", lat);

    let (ra, _) = eq_frm_ecl!(30.0 * f64::consts::PI / 180.0, 0.0, tilt);
    let ecl_long = coords::ecl_long_frm_eq(ra, 0.0, tilt);
    println!("ecl_long = {}", ecl_long * 180.0 / f64::consts::PI);
    println!("ra for 30 is {}", ra * 180.0 / f64::consts::PI);
    println!(
        "ra hh:mm:ss: {:?}",
        hms_frm_deg(ra * 180.0 / f64::consts::PI)
    );

    let day_start = astro::time::DayOfMonth {
        day: 5,
        hr: 0,
        min: 0,
        sec: 0.0,
        time_zone: -7.0,
    };
    let d = astro::time::decimal_day(&day_start);

    let date = astro::time::Date {
        year: 2025,
        month: astro::time::Month::Jan,
        decimal_day: d,
        cal_type: astro::time::CalType::Gregorian,
    };
    let julian_day = astro::time::julian_day(&date);
    let delta_t = astro::time::delta_t(date.year.into(), date.month as u8);

    let jd = astro::time::julian_ephemeris_day(julian_day, delta_t);
    let foo = zenith2(jd, -122.0_f64.to_radians(), 37.77_f64.to_radians());
    println!(
        "Zenith at midnight jan 5 (Lon {}, Lat {})",
        foo.long.to_degrees(),
        foo.lat.to_degrees()
    );
    // println!("free_eq (RA {}, DEC {})", foo_asc.to_degrees(), foo_dec.to_degrees());
    for a in 0..36 {
        let dec_day = astro::time::decimal_day(&day_start) + a as f64 * 40.0 / (60.0 * 24.0);

        let date = astro::time::Date {
            year: 2025,
            month: astro::time::Month::Jan,
            decimal_day: dec_day,
            cal_type: astro::time::CalType::Gregorian,
        };
        let julian_day = astro::time::julian_day(&date);
        let delta_t = astro::time::delta_t(date.year.into(), date.month as u8);

        let jd = astro::time::julian_ephemeris_day(julian_day, delta_t);

        let east = east_horizon(jd, local_long.to_radians(), lat);
        let z = zenith(jd, local_long.to_radians(), lat);
        let west = west_horizon(jd, local_long.to_radians(), lat);

        println!("Time: {:?} East: {}, Zenith: {}, West: {}", hms_from_decimal_day(dec_day, -8.0), east.long.in2pi().to_degrees(), z.long.in2pi().to_degrees(), west.long.in2pi().to_degrees());
    }
    println!("Experiment to go from ecliptic to equatorial coordinates and back again");

    let (asc, dec) = eq_frm_ecl!(30.0_f64.to_radians(), 45.0_f64.to_radians(), tilt);
    println!(
        "Lon/Lat (30, 45) in ecliptic is ({} RA, {} Dec)",
        asc.to_degrees(),
        dec.to_degrees()
    );

    let (lon, lat) = ecl_frm_eq!(asc, dec, tilt);
    println!(
        "RA/Dec ({}, {}) in equatorial is ({} lon, {} lat)",
        asc.to_degrees(),
        dec.to_degrees(),
        lon.to_degrees(),
        lat.to_degrees()
    );

    let z = zenith(
        julian_ephm_day,
        -122.4_f64.to_radians(),
        37.77_f64.to_radians(),
    );
    println!("Zenith longitude: {} degrees", z.long.in2pi().to_degrees());
    println!(
        "Zenith equitorial: {}, {}",
        eq_frm_ecl!(z.long, z.lat, tilt).0.to_degrees(),
        eq_frm_ecl!(z.long, z.lat, tilt).1.to_degrees()
    );

    let east_horizon_az = 90.0_f64.to_radians();
    let east_horizon = eq_from_hz(east_horizon_az, 0.0, local_sd, 37.77_f64.to_radians());
    println!(
        "East horizon position: (RA {}, Dec: {})",
        east_horizon.asc.to_degrees(),
        east_horizon.dec.to_degrees()
    );
    let (east_lon, east_lat) = ecl_frm_eq!(east_horizon.asc, east_horizon.dec, tilt);
    println!(
        "East horizon ecliptic: (Lat {}, Lon {})",
        east_lat.to_degrees(),
        east_lon.to_degrees()
    );

    let west_horizon_az = 270.0_f64.to_radians();
    let west_horizon = eq_from_hz(west_horizon_az, 0.0, local_sd, 37.77_f64.to_radians());
    println!(
        "West horizon position: (RA {}, Dec: {})",
        west_horizon.asc.to_degrees(),
        west_horizon.dec.to_degrees()
    );
    let (west_lon, west_lat) = ecl_frm_eq!(west_horizon.asc, west_horizon.dec, tilt);
    println!(
        "East horizon ecliptic: (Lat {}, Lon {})",
        west_lat.to_degrees(),
        limit_to_360(west_lon.to_degrees())
    );
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

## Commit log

2025-01-23 initial commmit of astro-medallion. Kicad project and controller code
    [astro-medallion.kicad_pcb, astro-medallion.kicad_sch]
2025-01-23 reversed the labels of the signs to increase counter-clockwise
    [astro-medallion.kicad_pcb]
2026-01-17 committing everything that's part of the current production of astro medallion
